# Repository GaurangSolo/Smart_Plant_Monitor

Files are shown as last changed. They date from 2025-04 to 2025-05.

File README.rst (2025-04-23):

# XIAO Smart Plant Monitor Project (or Blinky Example)

This project uses the Zephyr RTOS on a Seeed Studio XIAO nRF52840 board. Development is done using VS Code with the nRF Connect Extension Pack.

## Project Structure

This is set up as a "Freestanding" Zephyr application. It relies on the Zephyr installation identified by the `ZEPHYR_BASE` environment variable but does not contain its own `.west` workspace configuration directory.

## Prerequisites

* Zephyr RTOS and SDK installed (follow official Zephyr Getting Started Guide).
* `ZEPHYR_BASE` environment variable set correctly at the **System or User level** so that external tools invoked by VS Code (like the task runner) can find the Zephyr installation. (This is needed for `west` extension commands like `flash` to be recognized).
* VS Code with the nRF Connect Extension Pack installed.

## Building the Code

1.  Open this project folder (`blinky_working` or `XIAO_SPM_v1.0`) in VS Code.
2.  Use the nRF Connect extension view (Nordic logo icon in the sidebar).
3.  Under "APPLICATIONS", find this project.
4.  Ensure a "Build Configuration" exists targeting the correct board (`xiao_ble` or `xiao_ble/nrf52840/sense`). If not, add one.
5.  Click the "Build" action (hammer icon) next to the build configuration.

## Flashing the Board (Using Custom UF2 Task)

The Seeed Studio XIAO nRF52840 uses a UF2 bootloader, which allows flashing by copying a `.uf2` file to the board when it's acting as a USB drive.

Due to this project being a freestanding application and the desire to avoid setting system-wide defaults, a custom VS Code task is defined in `.vscode/tasks.json` to handle UF2 flashing specifically for this project.

**Steps to Flash:**

1.  **Connect** the XIAO nRF52840 board to your computer via USB C.
2.  **Enter UF2 Bootloader Mode:** Quickly **double-press the `RST` (Reset) button** on the board. The onboard yellow/orange LED should start pulsing slowly, and your computer should mount a USB drive named `XIAO BLE`.
3.  **Run the Custom Task:**
    * In VS Code, open the Command Palette: `Ctrl+Shift+P` (or `Cmd+Shift+P` on Mac).
    * Type `Tasks: Run Task` and select it.
    * Choose the task labeled **`Flash XIAO with UF2`** from the list that appears.
4.  **Monitor Output:** Check the VS Code terminal output. You should see `west flash --runner uf2` being executed and confirmation of the file being copied. The board will automatically reset and run the new firmware after flashing.

**(Optional) Binding Task to Flash Button:** If you prefer to use the standard "Flash" button in the nRF Connect extension view, you can try binding the custom task to it by adding the following to your `.vscode/settings.json` file:

```json
{
    "nrf-connect.taskBindings": {
        "Flash": "Flash XIAO with UF2"
    }
}

---------------------------------------------------------------------------------------------------------------------------------------------------------------------------------------------------------------------------------------------------------------------
.. zephyr:code-sample:: blinky
   :name: Blinky
   :relevant-api: gpio_interface

   Blink an LED forever using the GPIO API.

Overview
********

The Blinky sample blinks an LED forever using the :ref:`GPIO API <gpio_api>`.

The source code shows how to:

#. Get a pin specification from the :ref:`devicetree <dt-guide>` as a
   :c:struct:`gpio_dt_spec`
#. Configure the GPIO pin as an output
#. Toggle the pin forever

See :zephyr:code-sample:`pwm-blinky` for a similar sample that uses the PWM API instead.

.. _blinky-sample-requirements:

Requirements
************

Your board must:

#. Have an LED connected via a GPIO pin (these are called "User LEDs" on many of
   Zephyr's :ref:`boards`).
#. Have the LED configured using the ``led0`` devicetree alias.

Building and Running
********************

Build and flash Blinky as follows, changing ``reel_board`` for your board:

.. zephyr-app-commands::
   :zephyr-app: samples/basic/blinky
   :board: reel_board
   :goals: build flash
   :compact:

After flashing, the LED starts to blink and messages with the current LED state
are printed on the console. If a runtime error occurs, the sample exits without
printing to the console.

Build errors
************

You will see a build error at the source code line defining the ``struct
gpio_dt_spec led`` variable if you try to build Blinky for an unsupported
board.

On GCC-based toolchains, the error looks like this:

.. code-block:: none

   error: '__device_dts_ord_DT_N_ALIAS_led_P_gpios_IDX_0_PH_ORD' undeclared here (not in a function)

Adding board support
********************

To add support for your board, add something like this to your devicetree:

.. code-block:: DTS

   / {
   	aliases {
   		led0 = &myled0;
   	};

   	leds {
   		compatible = "gpio-leds";
   		myled0: led_0 {
   			gpios = <&gpio0 13 GPIO_ACTIVE_LOW>;
                };
   	};
   };

The above sets your board's ``led0`` alias to use pin 13 on GPIO controller
``gpio0``. The pin flags :c:macro:`GPIO_ACTIVE_HIGH` mean the LED is on when
the pin is set to its high state, and off when the pin is in its low state.

Tips:

- See :dtcompatible:`gpio-leds` for more information on defining GPIO-based LEDs
  in devicetree.

- If you're not sure what to do, check the devicetrees for supported boards which
  use the same SoC as your target. See :ref:`get-devicetree-outputs` for details.

- See :zephyr_file:`include/zephyr/dt-bindings/gpio/gpio.h` for the flags you can use
  in devicetree.

- If the LED is built in to your board hardware, the alias should be defined in
  your :ref:`BOARD.dts file <devicetree-in-out-files>`. Otherwise, you can
  define one in a :ref:`devicetree overlay <set-devicetree-overlays>`.

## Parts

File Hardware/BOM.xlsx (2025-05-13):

Reference | Value | Purchase Link | Manufacturer | Part Number | Price | Qty
ANT1 | ANT2012LL00R2400A | ANT2012LL00R2400A Pulse Electronics | RF and Wireless | DigiKey (https://www.digikey.ca/en/products/detail/pulse-electronics/ANT2012LL00R2400A/9360375) | Pulse Electronics | ANT2012LL00R2400A | 0.39 | 1
C1, C3, C5, C7, C14, C19, C21 | 0.1uF | CL05B104KP5NNNC Samsung Electro-Mechanics | Capacitors | DigiKey (https://www.digikey.ca/en/products/detail/samsung-electro-mechanics/CL05B104KP5NNNC/3886660) | Samsung Electro-Mechanics | CL05B104KP5NNNC | 0.0053 | 7
C2, C6, C8, C18 | 10uF | GRM155R61A106ME11D Murata Electronics | Capacitors | DigiKey (https://www.digikey.ca/en/products/detail/murata-electronics/GRM155R61A106ME11D/12091056) | Murata Electronics | GRM155R61A106ME11D | 0.0365 | 4
C4, C13, C17, C27 | 1uF | CL05A105KA5NQNC Samsung Electro-Mechanics | Capacitors | DigiKey (https://www.digikey.ca/en/products/detail/samsung-electro-mechanics/CL05A105KA5NQNC/3887103) | Samsung Electro-Mechanics | CL05A105KA5NQNC | 0.0459 | 4
C11, C12 | 8pF | CL05C080DB51PNC Samsung Electro-Mechanics | Capacitors | DigiKey (https://www.digikey.ca/en/products/detail/samsung-electro-mechanics/CL05C080DB51PNC/11487821) | Samsung Electro-Mechanics | CL05C080DB51PNC | 0.0249 | 2
C15, C16 | 1.2pF | GRM0335C1E1R2BA01D Murata Electronics | Capacitors | DigiKey (https://www.digikey.ca/en/products/detail/murata-electronics/GRM0335C1E1R2BA01D/4358580) | Murata Electronics | GRM0335C1E1R2BA01D | 0.0144 | 2
C22-C24 | 10uF | CL10A106KQ8NNNC Samsung Electro-Mechanics | Capacitors | DigiKey (https://www.digikey.ca/en/products/detail/samsung-electro-mechanics/CL10A106KQ8NNNC/3886696) | Samsung Electro-Mechanics | CL10A106KQ8NNNC | 0.0259 | 3
C25 | 2.2nF/2200pF | C0603C222K5RACTU KEMET | Capacitors | DigiKey (https://www.digikey.ca/en/products/detail/kemet/C0603C222K5RACTU/411084) | KEMET | C0603C222K5RACTU | 0.0247 | 1
C26 | 1uF | CL10B105KP8NNNC Samsung Electro-Mechanics | Capacitors | DigiKey (https://www.digikey.ca/en/products/detail/samsung-electro-mechanics/CL10B105KP8NNNC/3887604) | Samsung Electro-Mechanics | CL10B105KP8NNNC | 0.007 | 1
D1 | QBLP600-RGB | QBLP600-RGB QT Brightek (QTB) | Capacitors | DigiKey (https://www.digikey.ca/en/products/detail/qt-brightek-qtb/QBLP600-RGB/5299203) | QT Brightek (QTB) | QBLP600-RGB | 0.389 | 1
D2 | HSP053-4M5 | HSP053-4M5 STMicroelectronics | Capacitors | DigiKey (https://www.digikey.ca/en/products/detail/stmicroelectronics/HSP053-4M5/8570685) | STMicroelectronics | HSP053-4M5 | 0.1463 | 1
F1 | 1206L110/16WR | 1206L110/16WR Littelfuse Inc. | Capacitors | DigiKey (https://www.digikey.ca/en/products/detail/littelfuse-inc/1206L110-16WR/3997167) | Littelfuse Inc. | 1206L110/16WR | 0.934 | 1
J2 | USB4160-03-0230-C | USB4160-03-0230-C GCT | Capacitors | DigiKey (https://www.digikey.ca/en/products/detail/gct/USB4160-03-0230-C/16649097) | GCT | USB4160-03-0230-C | 1.2583 | 1
J3 | SM02B-SURS-TF | SM02B-SURS-TF JST Sales America Inc. | Capacitors | DigiKey (https://www.digikey.ca/en/products/detail/jst-sales-america-inc/SM02B-SURS-TF-LF-SN/1634780) | JST Sales America Inc. | SM02B-SURS-TF | 0.5836 | 1
JP1 | Jumper_2_Bridged |  |  | DNP |  | 1
L1 | 2.0nH | LQG15HN2N0C02D Murata Electronics | Capacitors | DigiKey (https://www.digikey.ca/) | Murata Electronics | LQG15HN2N0C02D | 0.0526 | 1
L2 | 2.7nH | LQP03TN2N7B02D Murata Electronics | Capacitors | DigiKey (https://www.digikey.ca/en/products/detail/murata-electronics/LQP03TN2N7B02D/2391744) | Murata Electronics | LQP03TN2N7B02D | 0.0353 | 1
L3 | 2.2ÂµH | CS160808-2R2K Bourns Inc. | Capacitors | DigiKey (https://www.digikey.ca/en/products/detail/bourns-inc/CS160808-1R2K/3782637) | Bourns Inc. | CS160808-2R2K | 0.0906 | 1
R1 | 1.5k | ERJ-2GEJ152X Panasonic Electronic Components | Capacitors | DigiKey (https://www.digikey.ca/en/products/detail/panasonic-electronic-components/ERJ-2GEJ152X/146914) | Panasonic Electronic Components | ERJ-2GEJ152X | 0.0196 | 1
R2 | 40.2R | RMCF0402FT40R2 Stackpole Electronics Inc | Capacitors | DigiKey (https://www.digikey.com/en/products/detail/stackpole-electronics-inc/RMCF0402FT40R2/1714715) | Stackpole Electronics Inc | RMCF0402FT40R2 | 0.0135 | 1
R3, R4, R17, R18 | 5.1k | RC0402FR-075K1L YAGEO | Capacitors | DigiKey (https://www.digikey.ca/en/products/detail/yageo/RC0402FR-075K1L/726624) | YAGEO | RC0402FR-075K1L | 0.0096 | 4
R5, R9, R14, R15 | 499R | RC0402FR-07499RL YAGEO | Capacitors | DigiKey (https://www.digikey.ca/en/products/detail/yageo/RC0402FR-07499RL/726623) | YAGEO | RC0402FR-07499RL | 0.0096 | 4
R7 | 47k | RC0402FR-0747KL YAGEO | Capacitors | DigiKey (https://www.digikey.ca/en/products/detail/yageo/RC0402FR-0747KL/726616) | YAGEO | RC0402FR-0747KL | 0.0111 | 1
R8 | 100k | RC0402JR-07100KL YAGEO | Capacitors | DigiKey (https://www.digikey.ca/en/products/detail/yageo/RC0402JR-07100KL/726416) | YAGEO | RC0402JR-07100KL | 0.008 | 1
R10-R13, R16, R19 | 10k | RC0402JR-0710KL YAGEO | Capacitors | DigiKey (https://www.digikey.ca/en/products/detail/yageo/RC0402JR-0710KL/726418) | YAGEO | RC0402JR-0710KL | 0.0096 | 6
R20 | 60.4R | TFA0402R6042F-T10 Thin Film Technology Corp. | Capacitors | DigiKey (https://www.digikey.com/en/products/detail/thin-film-technology-corp/TFA0402R6042F-T10/23598478) | Thin Film Technology Corp. | TFA0402R6042F-T10 | 0.0134 | 1
R21 | 220R | RC0402FR-07220RL YAGEO | Capacitors | DigiKey (https://www.digikey.ca/en/products/detail/yageo/RC0402FR-07220RL/726565) | YAGEO | RC0402FR-07220RL | 0.0096 | 1
TC1 | DNP | TC2030-IDC Tag-Connect LLC | Capacitors | DigiKey (https://www.digikey.ca/en/products/detail/tag-connect-llc/TC2030-IDC/4571121) | Tag-Connect LLC | TC2030-IDC |  | 1
TP1-TP15 | DNP |  |  | DNP |  | 15
U1 | BME280 | BME280 Bosch Sensortec | Capacitors | DigiKey (https://www.digikey.ca/en/products/detail/bosch-sensortec/BME280/6136306) | Bosch Sensortec | BME280 | 4.7649 | 1
U2 | W25Q64JVXGIQ TR | W25Q64JVXGIQ TR Winbond Electronics | Capacitors | DigiKey (https://www.digikey.ca/en/products/detail/winbond-electronics/W25Q64JVXGIQ-TR/15181863) | Winbond Electronics | W25Q64JVXGIQ TR | 1.3578 | 1
U3 | NPM1100-QDAA-R | NPM1100-QDAA-R Nordic Semiconductor | Capacitors | DigiKey (https://www.digikey.ca/en/products/detail/nordic-semiconductor-asa/NPM1100-QDAA-R/18069437) | Nordic Semiconductor | NPM1100-QDAA-R | 1.4698 | 1
U4 | ESP32-C6 | ESP32-C6 Espressif Systems | Capacitors | DigiKey (https://www.digikey.ca/en/products/detail/espressif-systems/ESP32-C6/18587530) | Espressif Systems | ESP32-C6 | 3.18 | 1
U7 | DEA162500LT-1217A1 | DEA162500LT-1217A1 TDK Corporation | Capacitors | DigiKey (https://www.digikey.ca/en/products/detail/tdk-corporation/DEA162500LT-1217A1/1211469) | TDK Corporation | DEA162500LT-1217A1 | 0.2966 | 1
X1 | R2520-40.000-8-F-1010-TR-NS3 | R2520-40.000-8-F-1010-TR-NS3 Raltron Electronics | Capacitors | DigiKey (https://www.digikey.ca/en/products/detail/raltron-electronics/R2520-40-000-8-F-1010-TR-NS3/22531210) | Raltron Electronics | R2520-40.000-8-F-1010-TR-NS3 | 0.2363 | 1

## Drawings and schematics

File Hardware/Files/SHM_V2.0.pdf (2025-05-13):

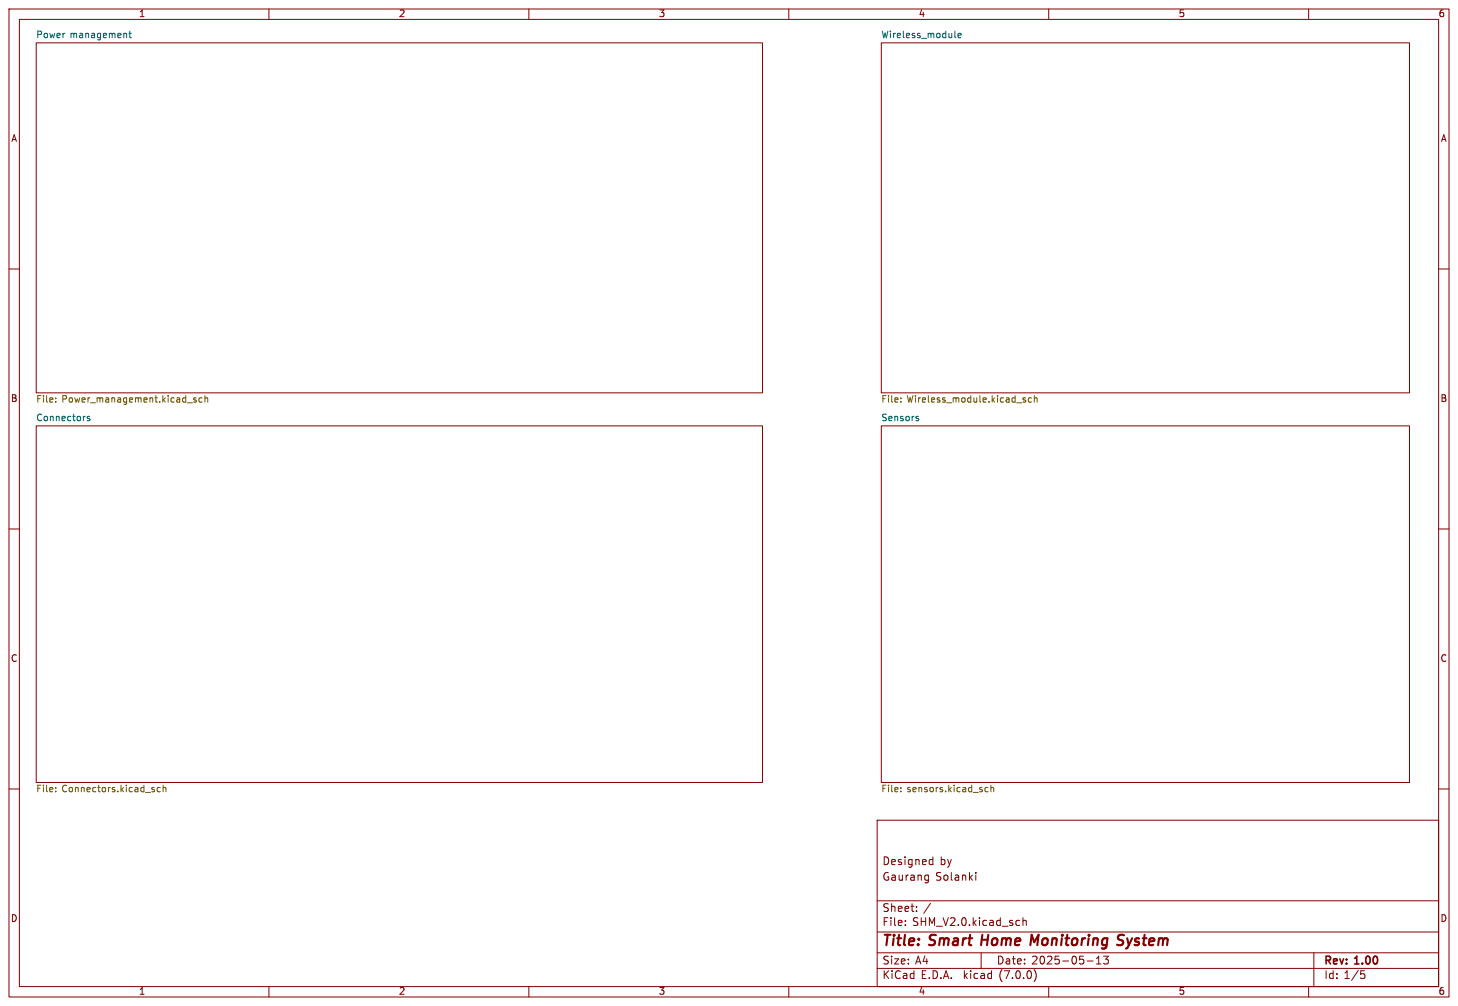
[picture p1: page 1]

Wireless_module File: Wireless_module.kicad_sch Connectors File: Connectors.kicad_sch

Id: 1/5 Title: Smart Home Monitoring System

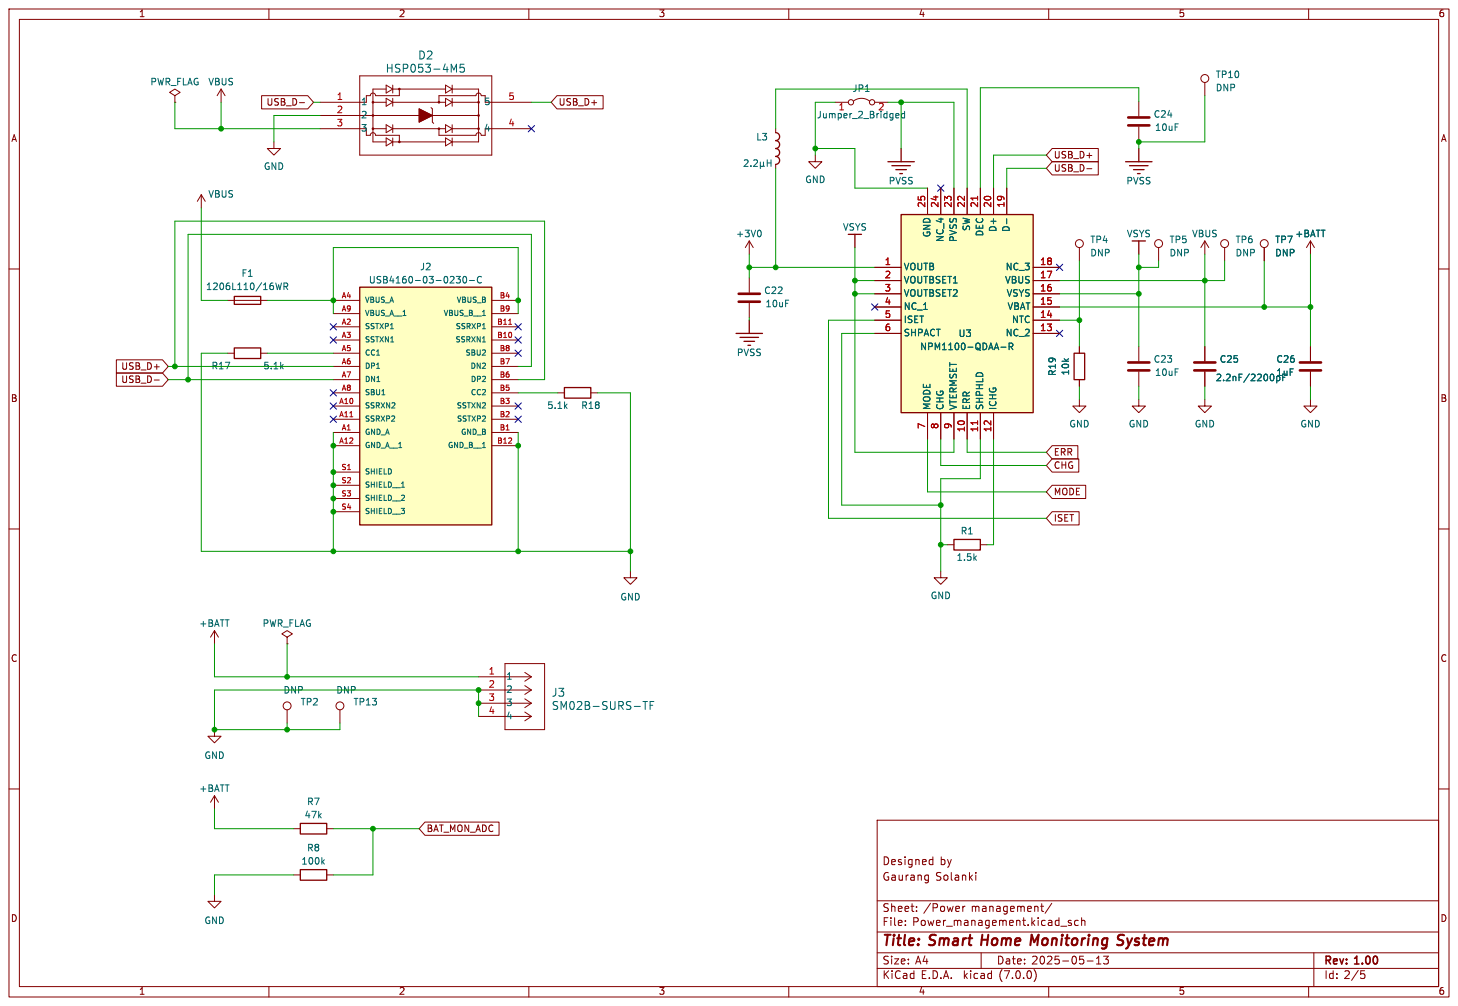
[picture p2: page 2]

File: Power_management.kicad_sch Sheet: /Power management/
Id: 2/5 Title: Smart Home Monitoring System

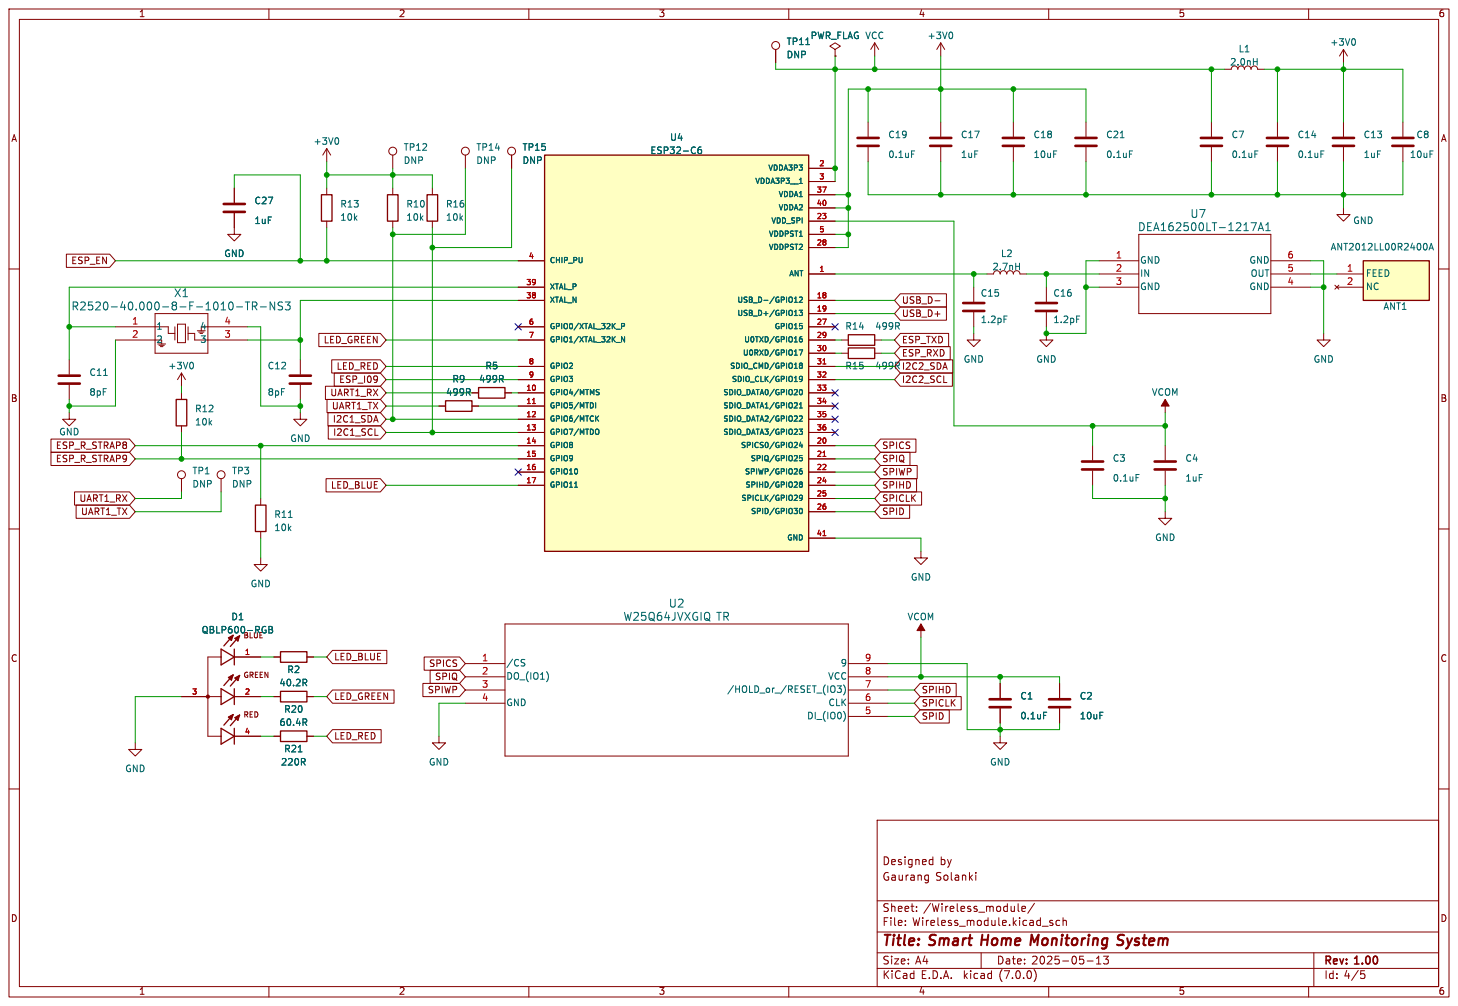
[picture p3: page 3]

File: Wireless_module.kicad_sch Sheet: /Wireless_module/
Id: 4/5 Title: Smart Home Monitoring System

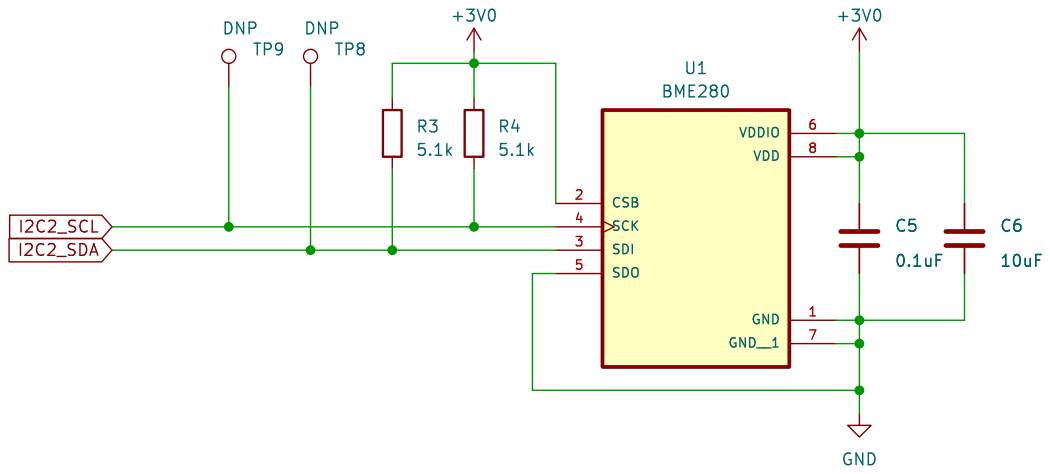
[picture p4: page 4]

Id: 5/5 Title: Smart Home Monitoring System

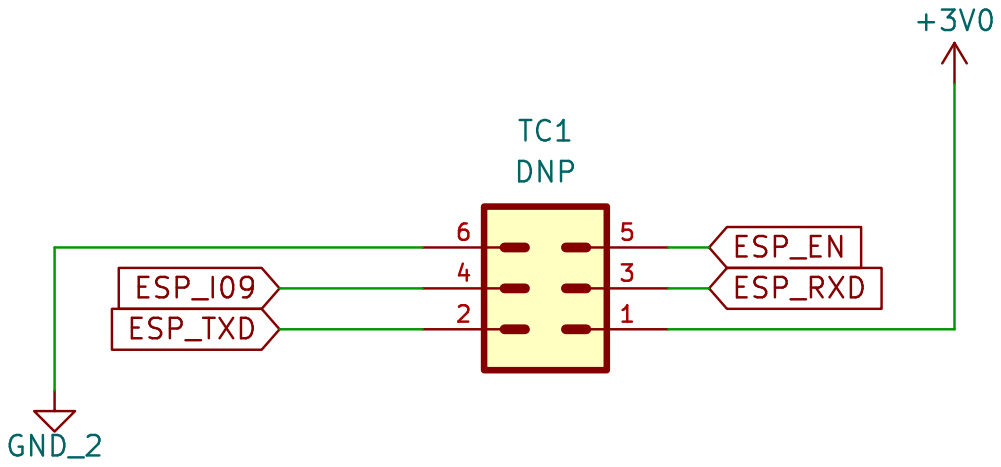
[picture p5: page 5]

Id: 6/5 Title: Smart Home Monitoring System

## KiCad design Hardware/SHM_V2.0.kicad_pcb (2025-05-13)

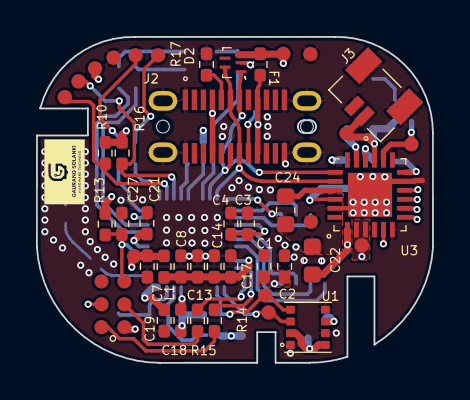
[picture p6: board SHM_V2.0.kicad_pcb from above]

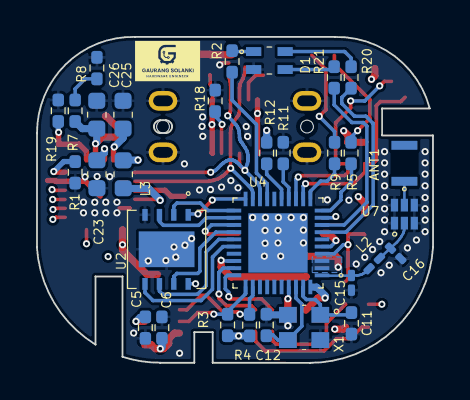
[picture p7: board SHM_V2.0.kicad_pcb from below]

Board: 4 copper layers, 22.0 x 18.1 mm, 76 parts (31 on the bottom side), 51 nets.

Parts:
ANT1: ANT2012LL00R2400A; ANTC2012X120N
C1, C3, C5, C7, C14, C19, C21: 0.1uF; R_0402_1005Metric_Pad0.72x0.64mm_HandSolder
C2: locked; R_0402_1005Metric_Pad0.72x0.64mm_HandSolder
C4, C13, C17, C27: 1uF; R_0402_1005Metric_Pad0.72x0.64mm_HandSolder
C6, C8, C18: 10uF; R_0402_1005Metric_Pad0.72x0.64mm_HandSolder
C11, C12: 8pF; R_0402_1005Metric_Pad0.72x0.64mm_HandSolder
C15, C16: 1.2pF; C_0201_0603Metric_Pad0.64x0.40mm_HandSolder
C22, C23, C24: 10uF; C_0603_1608Metric
C25: 2.2nF; C_0603_1608Metric
C26: 1uF; C_0603_1608Metric
D1: QBLP600-RGB; LED_QBLP600-RGB
D2: HSP053-4M5; MICROQFN-5L_STM
F1: 1206L110/16WR; R_0402_1005Metric_Pad0.72x0.64mm_HandSolder
J2: USB4160-03-0230-C_REVA2; GCT_USB4160-03-0230-C_REVA2
J3: SM02B-SURS-TF; CONN_SM02B-SURS-TF_JST
JP1: Jumper_2_Bridged; Jumper
L1: 2.0nH; R_0402_1005Metric_Pad0.72x0.64mm_HandSolder
L2: 2.7nH; C_0201_0603Metric_Pad0.64x0.40mm_HandSolder
L3: 2.2µH; C_0603_1608Metric
R1: 1.5k; R_0402_1005Metric_Pad0.72x0.64mm_HandSolder
R2: 40R; R_0402_1005Metric_Pad0.72x0.64mm_HandSolder
R3, R4, R17, R18: 5.1k; R_0402_1005Metric_Pad0.72x0.64mm_HandSolder
R5, R9, R14, R15: 499R; R_0402_1005Metric_Pad0.72x0.64mm_HandSolder
R7: 47k; R_0402_1005Metric_Pad0.72x0.64mm_HandSolder
R8: 100k; R_0402_1005Metric_Pad0.72x0.64mm_HandSolder
R10, R11, R12, R13, R16, R19: 10k; R_0402_1005Metric_Pad0.72x0.64mm_HandSolder
R20: 60R; R_0402_1005Metric_Pad0.72x0.64mm_HandSolder
R21: 220R; R_0402_1005Metric_Pad0.72x0.64mm_HandSolder
TC1: DNP; TC2030-IDC-NL2
TP1, TP2, TP3, TP4, TP5, TP6, TP7, TP8, TP9, TP10, TP11, TP12, TP13, TP14, TP15: DNP; TestPoint_Pad_D1.0mm
U1: BME280; PSON65P250X250X100-8N
U2: W25Q64JVXGIQ TR; DFN_XGIQ TR_WIN-L
U3: NPM1100-QDAA-R; QFN50P400X400X100-25N
U4: ESP32-C6; QFN40P500X500X90-41N
U7: DEA162500LT-1217A1; DEA-6_1P6X0P8
X1: R2520-40.000-8-F-1010-TR-NS3; R2520-40.000-10-F-1010-EXT-TR_RAL

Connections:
+3V0: C5.1, C6.1, C8.1, C13.1, C14.1, C17.1, C18.1, C19.1, C21.1, C22.1, L1.2, L3.2, R3.2, R4.2, R10.2, R12.2, R13.2, R16.2, TC1.1, TP12.1, U1.2 (CSB), U1.6 (VDDIO), U1.8 (VDD), U3.1 (VOUTB), U4.5 (VDDPST1), U4.28 (VDDPST2), U4.37 (VDDA1), U4.40 (VDDA2)
+BATT: C26.1, J3.1, R7.1, TP7.1, U3.15 (VBAT)
BAT_MON_ADC: R7.2, R8.1
ESP_EN: C27.1, R13.1, TC1.5, U4.4 (CHIP_PU)
ESP_I09: TC1.4, U4.9 (GPIO3)
ESP_RXD: R15.1, TC1.3
ESP_R_STRAP8: R11.2, U4.14 (GPIO8)
ESP_R_STRAP9: R12.1, U4.15 (GPIO9)
ESP_TXD: R14.1, TC1.2
GND: C1.2, C2.2, C3.2, C4.2, C5.2, C6.2, C7.2, C8.2, C11.2, C12.2, C13.2, C14.2, C15.2, C16.2, C17.2, C18.2, C19.2, C21.2, C23.2, C25.2, C26.2, C27.2, D1.3, D2.2, J2.A1 (GND_A), J2.A12 (GND_A__1), J2.B1 (GND_B), J2.B12 (GND_B__1), J2.S1 (SHIELD), J2.S2 (SHIELD__1), J2.S3 (SHIELD__2), J2.S4 (SHIELD__3), J3.2, J3.3, J3.4, R1.2, R8.2, R11.1, R17.1, R18.1, R19.1, TP2.1, TP13.1, U1.1 (GND), U1.5 (SDO), U1.7 (GND__1), U2.4 (GND), U2.9, U3.6 (SHPACT), U3.11 (SHPHLD), U3.25 (GND), U4.41 (GND), U7.1 (GND), U7.3 (GND), U7.4 (GND), U7.6 (GND), X1.2, X1.4
I2C1_SCL: R16.1, TP15.1, U4.13 (GPIO7/MTDO)
I2C1_SDA: R10.1, TP14.1, U4.12 (GPIO6/MTCK)
I2C2_SCL: R4.1, TP9.1, U1.4 (SCK), U4.32 (SDIO_CLK/GPIO19)
I2C2_SDA: R3.1, TP8.1, U1.3 (SDI), U4.31 (SDIO_CMD/GPIO18)
LED_BLUE: R2.2, U4.17 (GPIO11)
LED_GREEN: R20.2, U4.7 (GPIO1/XTAL_32K_N)
LED_RED: R21.2, U4.8 (GPIO2)
unnamed: ANT1.1 (FEED), U7.5 (OUT)
unnamed: D1.1, R2.1
unnamed: D1.2, R20.1
unnamed: D1.4, R21.1
unnamed: J2.A5 (CC1), R17.2
unnamed: J2.B5 (CC2), R18.2
unnamed: F1.2, J2.A4 (VBUS_A), J2.A9 (VBUS_A__1), J2.B4 (VBUS_B), J2.B9 (VBUS_B__1)
unnamed: C24.1, U3.21 (DEC)
unnamed: R1.1, U3.12 (ICHG)
unnamed: R19.2, TP4.1, U3.14 (NTC)
unnamed: L3.1, U3.22 (SW)
unnamed: C15.1, L2.1, U4.1 (ANT)
unnamed: R5.1, U4.10 (GPIO4/MTMS)
unnamed: R9.1, U4.11 (GPIO5/MTDI)
unnamed: R15.2, U4.30 (U0RXD/GPIO17)
unnamed: R14.2, U4.29 (U0TXD/GPIO16)
unnamed: C12.1, U4.38 (XTAL_N), X1.3
unnamed: C11.1, U4.39 (XTAL_P), X1.1
unnamed: C16.1, L2.2, U7.2 (IN)
PVSS: C22.2, C24.2, TP10.1, U3.23 (PVSS)
SPICLK: U2.6 (CLK), U4.25 (SPICLK/GPIO29)
SPICS: U2.1 (/CS), U4.20 (SPICS0/GPIO24)
SPID: U2.5 (DI_(IO0)), U4.26 (SPID/GPIO30)
SPIHD: U2.7 (/HOLD_or_/RESET_(IO3)), U4.24 (SPIHD/GPIO28)
SPIQ: U2.2 (DO_(IO1)), U4.21 (SPIQ/GPIO25)
SPIWP: U2.3, U4.22 (SPIWP/GPIO26)
UART1_RX: R5.2, TP1.1
UART1_TX: R9.2, TP3.1
USB_D+: D2.5, J2.A6 (DP1), J2.B6 (DP2), U3.20 (D+), U4.19 (USB_D+/GPIO13)
USB_D-: D2.1, J2.A7 (DN1), J2.B7 (DN2), U3.19 (D-), U4.18 (USB_D-/GPIO12)
VBUS: C25.1, D2.3, F1.1, TP6.1, U3.17 (VBUS)
VCC: C7.1, L1.1, TP11.1, U4.2 (VDDA3P3), U4.3 (VDDA3P3__1)
VCOM: C1.1, C2.1, C3.1, C4.1, U2.8 (VCC), U4.23 (VDD_SPI)
VSYS: C23.1, TP5.1, U3.2 (VOUTBSET1), U3.3 (VOUTBSET2), U3.9 (VTERMSET), U3.16 (VSYS)

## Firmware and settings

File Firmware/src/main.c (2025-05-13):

#include <zephyr/kernel.h>
#include <zephyr/device.h>
#include <zephyr/devicetree.h>
#include <zephyr/drivers/sensor.h>
#include <zephyr/drivers/gpio.h>
#include <zephyr/sys/printk.h>
#include <stdio.h> // Used for sensor_value_to_double
#include <stdbool.h> // Used for boolean type

/* --- BME280 Setup --- */

// Get the device pointer from the devicetree node defined in the overlay
#define BME280_NODE DT_COMPAT_GET_ANY_STATUS_OKAY(bosch_bme280)
static const struct device *bme280_dev = DEVICE_DT_GET(BME280_NODE);

/* --- LED Setup (Using Blue LED - led2) --- */

// Use the alias "led2" defined for the board (Blue LED on XIAO - P0.06)
#define LED_NODE DT_ALIAS(led2)
#if DT_NODE_HAS_STATUS(LED_NODE, okay)
// If the node exists and is okay, create the gpio_dt_spec structure
static const struct gpio_dt_spec led_spec = GPIO_DT_SPEC_GET(LED_NODE, gpios);
#else
// If led2 alias isn't found or okay, generate a compile-time error
#error "Unsupported board: led2 devicetree alias is not defined or enabled"
#endif

/* --- Main Application Entry Point --- */
void main(void)
{
    // Variables for sensor readings and function return codes
    struct sensor_value temp, press, humidity;
    int ret;
    bool bme280_ready = false; // Flag to track sensor status

    printk("Zephyr BME280 + Blinky (Blue LED) on XIAO nRF52840\n");

    /* --- Check if LED is ready --- */
    // Check LED GPIO controller readiness
    if (!gpio_is_ready_dt(&led_spec)) {
        printk("Error: LED GPIO controller %s is not ready\n", led_spec.port->name);
        return; // Exit if LED GPIO not ready - Blinking is essential
    }

    /* --- Configure LED Pin --- */
    // Configure the LED pin as an output, start with it OFF (respecting ACTIVE_LOW)
    ret = gpio_pin_configure_dt(&led_spec, GPIO_OUTPUT_INACTIVE);
    if (ret < 0) {
        printk("Error %d: failed to configure LED pin\n", ret);
        return; // Exit if configuration fails
    }
    printk("Blue LED pin configured.\n");

    /* --- Check if BME280 is ready (but don't exit if not) --- */
    if (!device_is_ready(bme280_dev)) {
        printk("Warning: BME280 sensor device (%s) is not ready. Will skip sensor readings.\n", bme280_dev->name);
        bme280_ready = false; // Sensor is not ready
    } else {
        printk("BME280 sensor ready.\n");
        bme280_ready = true; // Sensor is ready
    }

    /* --- Infinite Loop for Reading and Blinking --- */
    while (1) {
        /* --- Toggle LED --- */
        // Flip the state of the LED (ON -> OFF or OFF -> ON)
        ret = gpio_pin_toggle_dt(&led_spec);
        if (ret < 0) {
            printk("Error %d: failed to toggle LED pin\n", ret);
            // Decide if you want to continue or stop on toggle failure
        }

        /* --- Read BME280 (only if it was ready during startup) --- */
        if (bme280_ready) {
            // Fetch a new sample from the sensor
            ret = sensor_sample_fetch(bme280_dev);
            if (ret != 0) {
                printk("BME280: Sample fetch failed (%d)\n", ret);
                // Optional: Set bme280_ready = false here if fetch fails repeatedly?
            } else {
                // Get specific channel values
                sensor_channel_get(bme280_dev, SENSOR_CHAN_AMBIENT_TEMP, &temp);
                sensor_channel_get(bme280_dev, SENSOR_CHAN_HUMIDITY, &humidity);
                sensor_channel_get(bme280_dev, SENSOR_CHAN_PRESS, &press);

                // Print the fetched values using printk (requires CONFIG_CBPRINTF_FP_SUPPORT=y)
                printk("Temp: %.2f C; Press: %.2f kPa; Humidity: %.2f %%\n",
                       sensor_value_to_double(&temp),
                       sensor_value_to_double(&press),
                       sensor_value_to_double(&humidity));
            }
        }
        // If bme280_ready is false, the code simply skips the fetch/read block

        /* Wait - this delay controls both the blink rate AND sensor reading frequency */
        /* The Blue LED will be ON for 2 seconds, then OFF for 2 seconds */
        k_sleep(K_MSEC(2000));
    }
}

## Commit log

2025-04-23 add BME280 reading
    - Integrated BME280 sensor reading (temp, pressure, humidity) via I2C0.
    - Updated prj.conf with necessary configurations for GPIO, I2C, Sensor,
    USB CDC Console, Printk, and float support.
    - Modified main loop to continue blinking the LED even if the BME280
    sensor fails to initialize or read.
    [main.c]
2025-05-13 Added hardware files and organized project files.
    - Added hardware design files including schematics, PCB layout, and BOM for the smart home monitoring system.
    - Organized project structure into /hardware and /firmware directories for clarity.
    - Included README files in respective folders to describe build and usage instructions.
    This commit sets up the foundation for further development and documentation.
    [BOM.xlsx, Connectors.kicad_sch, IMU.kicad_sch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]
